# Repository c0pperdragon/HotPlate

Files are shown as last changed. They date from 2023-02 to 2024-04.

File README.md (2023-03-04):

# HotPlate

Cheap DIY solution to make a heater for hot-plate soldering.

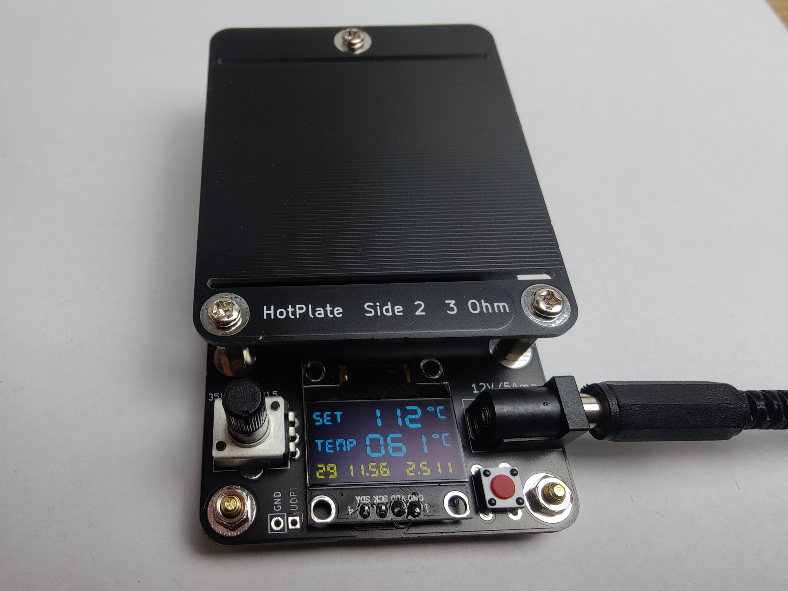
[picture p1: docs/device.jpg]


## Operating instructions

1. Plug the device to a common 12V DC power source that is able to provide 5 ampere.
2. Place the object to be soldered on the heater plate.
3. Switch on the heater with the red power button.
4. Select a target temperature (the "Set" value on the display) with the potentiometer.
5. When the solder is molten enough, turn off the heater with the red button. Note that
there is no support to automatically follow a temperature profile.

To switch the device between centigrade and fahrenheit, press the power button more than 
3 seconds when turning it on.

## Data shown on the display

* Set: Selected target temperature
* Temp: Temperature as measured

The numbers in the bottom area are used to understand the internal working and show the 
following things: 
* Duty cycle of the heater
* Supply voltage 
* Current through the top heater trace

## Theory of operation

The heater plate contains two copper traces (one at the top and one at the bottom) that can individually
be connected to the supply voltage. These traces have a resistance of about 3.5 ohm each (within
manufacturing tolerances) and will produce the heat for the process. For fine control of the output power,
the controller circuit will quickly turn each heater trace on and off.

To receive feeedback about the current temperature, the controller circuit contains a Hall-effect sensor
to monitor the electric current running through the top heater trace. Combined with the 
voltage that is also monitored, the resistance of this trace can be computed. As the specific resistance of
copper changes with temperature, the current temperature can be computed. 

Note that due to tolerances in PCB manufacturing and in the electronic parts, the temperature measurement
may be not very precise. You will need to experimentally find the best temperature setting for your specific application.

## Replacement heater plate

The repeated thermal stress on the heater will probably cause it to get damaged eventually. In this case
it is quite easy to have a replacement PCB made using the [Gerber files](heater/gerber).
As you will probably get multiple parts from your manufacturer, this should then last for a considerable 
time. 
You can also just turn over the heater plate if the top surface gets scratched or is otherwise worn out,
so you can continue to use it.

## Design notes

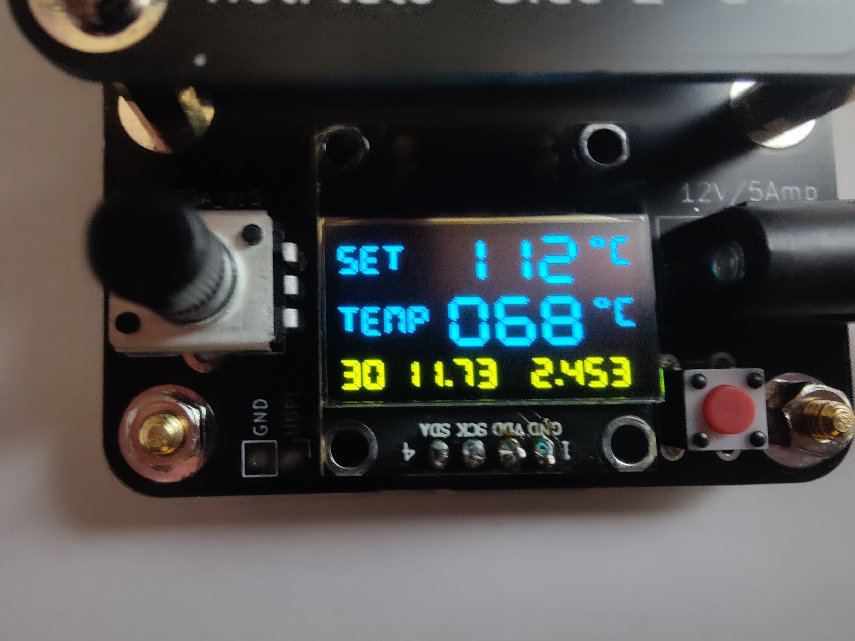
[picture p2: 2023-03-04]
docs/display.jpg

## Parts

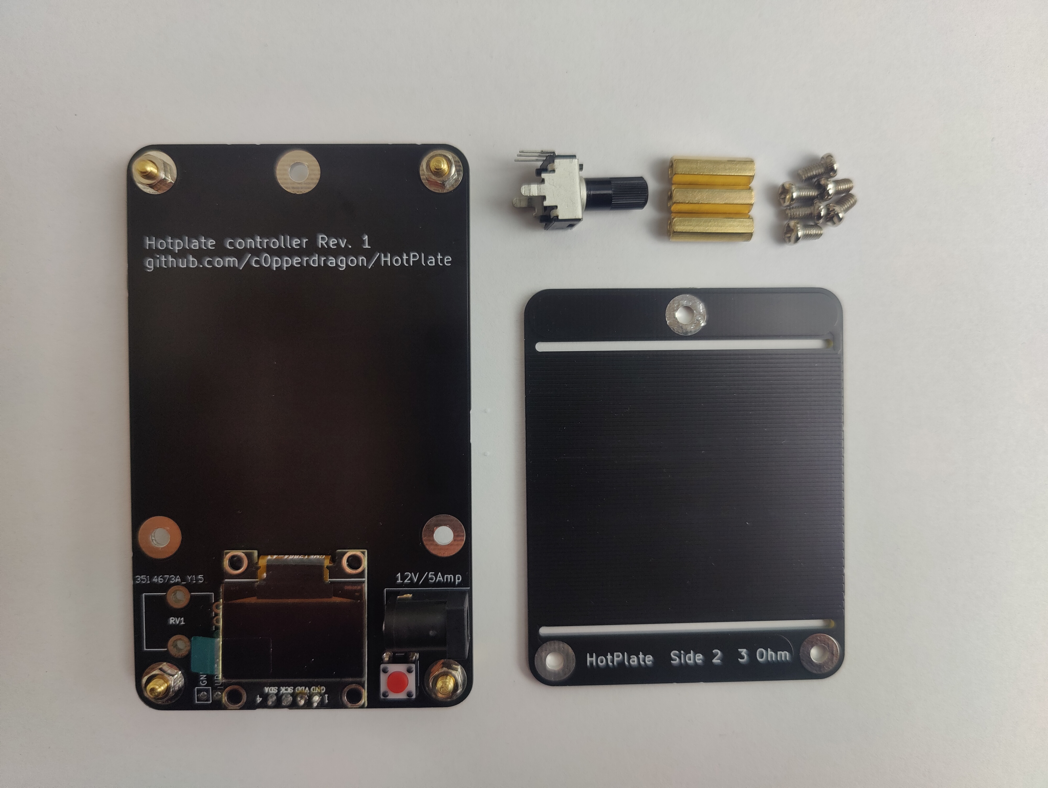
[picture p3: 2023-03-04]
docs/parts.jpg

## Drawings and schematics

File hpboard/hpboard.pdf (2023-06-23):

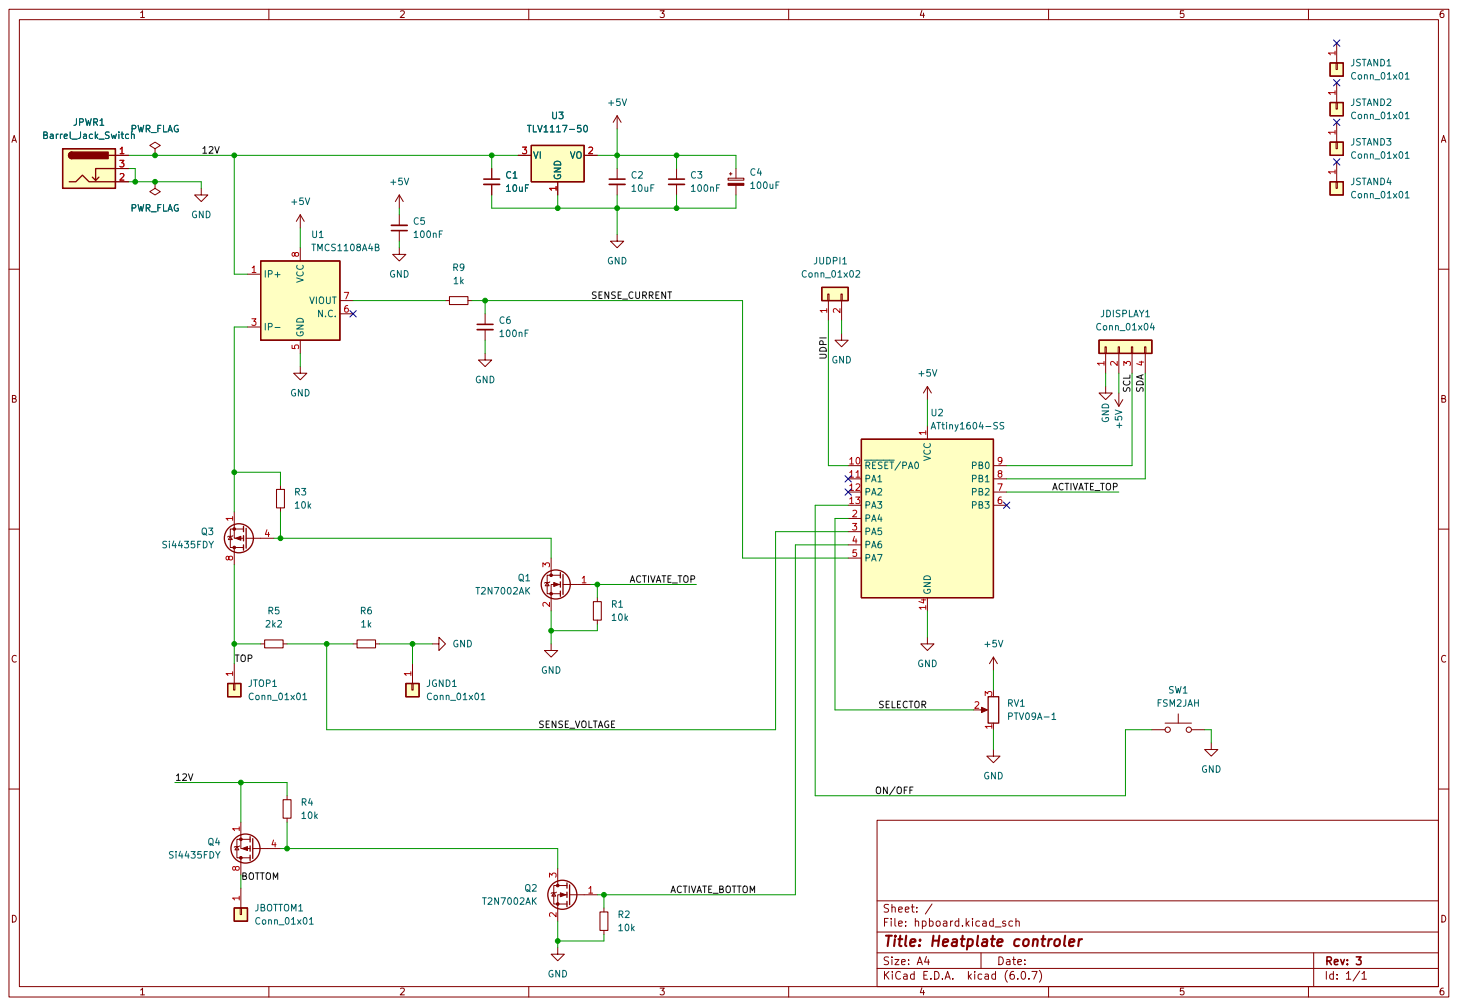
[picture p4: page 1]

File: hpboard.kicad_sch Sheet: / GND

Id: 1/1 Title: Heatplate controler

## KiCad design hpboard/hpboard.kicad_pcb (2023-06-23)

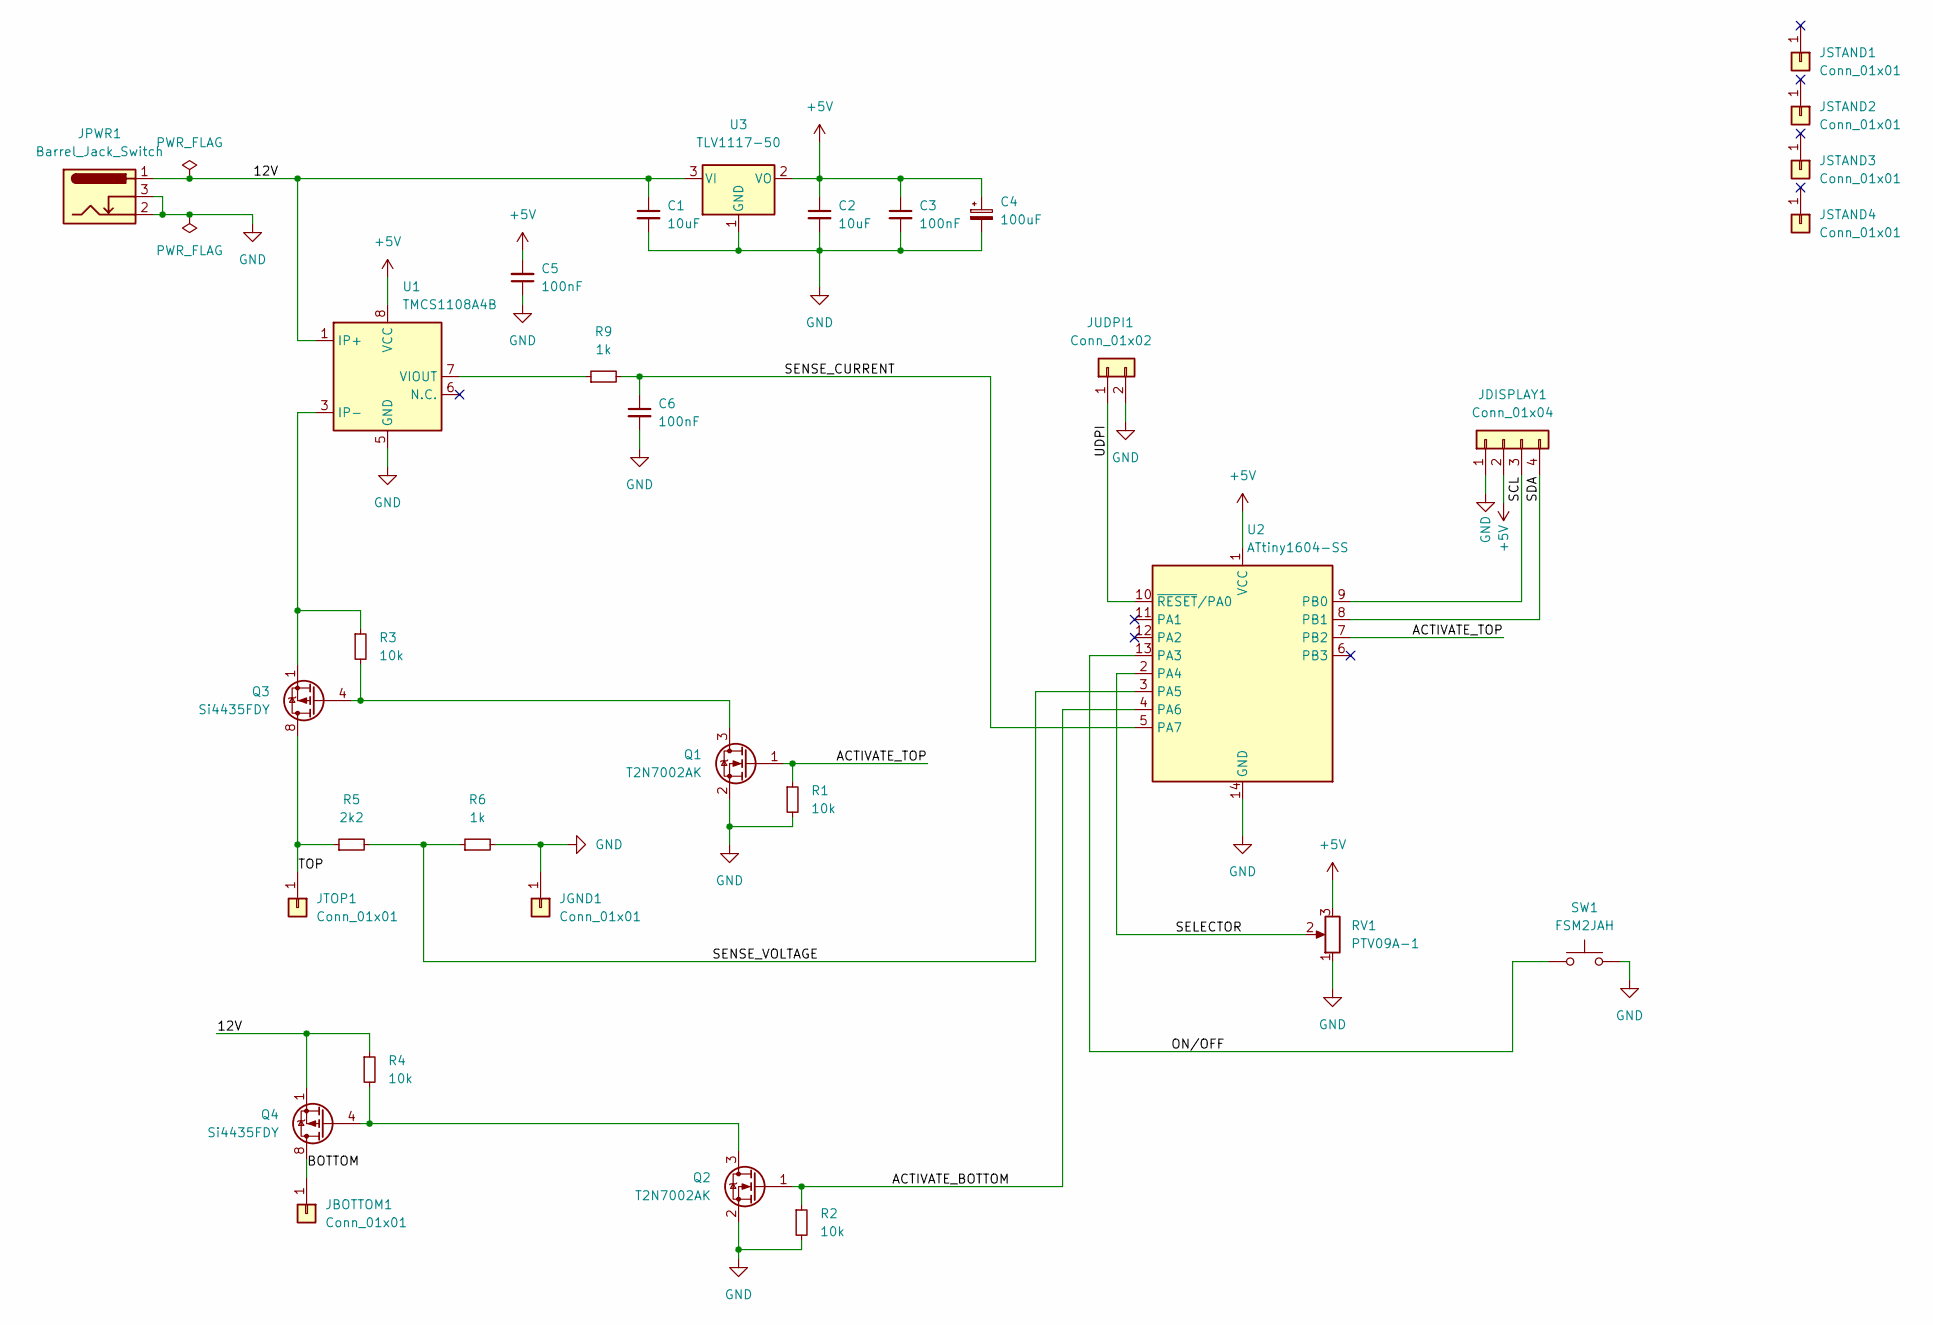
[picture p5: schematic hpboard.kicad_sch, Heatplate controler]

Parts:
C1, C2: 10uF; C_0805_2012Metric_Pad1.18x1.45mm_HandSolder
C3, C5, C6: 100nF; C_0603_1608Metric_Pad1.08x0.95mm_HandSolder
C4: 100uF; CP_EIA-3528-21_Kemet-B_Pad1.50x2.35mm_HandSolder
JBOTTOM1: Conn_01x01; MountingHole_3.2mm_Large
JDISPLAY1: Conn_01x04; PinHeader_1x04_P2.54mm_Vertical
JGND1: Conn_01x01; MountingHole_3.2mm_Large
JPWR1: Barrel_Jack_Switch; BarrelJack_Horizontal
JSTAND1, JSTAND2, JSTAND3, JSTAND4: Conn_01x01; MountingHole_3.2mm_Large
JTOP1: Conn_01x01; MountingHole_3.2mm_Large
JUDPI1: Conn_01x02; PinHeader_1x02_P2.54mm_Vertical
Q1, Q2: T2N7002AK; SOT-23
Q3, Q4: Si4435FDY; SOIC-8_3.9x4.9mm_P1.27mm
R1, R2, R3, R4: 10k; R_0805_2012Metric_Pad1.20x1.40mm_HandSolder
R5: 2k2; R_0805_2012Metric_Pad1.20x1.40mm_HandSolder
R6, R9: 1k; R_0805_2012Metric_Pad1.20x1.40mm_HandSolder
RV1: PTV09A-1; Potentiometer_Bourns_PTV09A-1_Single_Vertical
SW1: FSM2JAH; SW_PUSH_6mm
U1: TMCS1108A4B; SOIC-8_3.9x4.9mm_P1.27mm
U2: ATtiny1604-SS; SOIC-14_3.9x8.7mm_P1.27mm
U3: TLV1117-50; SOT-223-3_TabPin2

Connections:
+5V: C2.1, C3.1, C4.1, C5.2, JDISPLAY1.2, RV1.3, U1.8 (VCC), U2.1 (VCC), U3.2 (VO)
/12V: C1.1, JPWR1.1, Q4.1 (S), Q4.2 (S), Q4.3 (S), R4.1, U1.1 (IP+), U1.2 (IP+), U3.3 (VI)
/ACTIVATE_BOTTOM: Q2.1 (G), R2.1, U2.4 (PA6)
/ACTIVATE_TOP: Q1.1 (G), R1.1, U2.7 (PB2)
/BOTTOM: JBOTTOM1.1, Q4.5 (D), Q4.6 (D), Q4.7 (D), Q4.8 (D)
/ON/OFF: SW1.1, U2.13 (PA3)
/SCL: JDISPLAY1.3, U2.9 (PB0)
/SDA: JDISPLAY1.4, U2.8 (PB1)
/SELECTOR: RV1.2, U2.2 (PA4)
/SENSE_CURRENT: C6.1, R9.2, U2.5 (PA7)
/SENSE_VOLTAGE: R5.2, R6.1, U2.3 (PA5)
/TOP: JTOP1.1, Q3.5 (D), Q3.6 (D), Q3.7 (D), Q3.8 (D), R5.1
/UDPI: JUDPI1.1, U2.10 (~RESET/PA0)
GND: C1.2, C2.2, C3.2, C4.2, C5.1, C6.2, JDISPLAY1.1, JGND1.1, JPWR1.2, JPWR1.3, JUDPI1.2, Q1.2 (S), Q2.2 (S), R1.2, R2.2, R6.2, RV1.1, SW1.2, U1.5 (GND), U2.14 (GND), U3.1 (GND)
unnamed: Q1.3 (D), Q3.4 (G), R3.2
unnamed: Q2.3 (D), Q4.4 (G), R4.2
unnamed: Q3.1 (S), Q3.2 (S), Q3.3 (S), R3.1, U1.3 (IP-), U1.4 (IP-)
unnamed: R9.1, U1.7 (VIOUT)

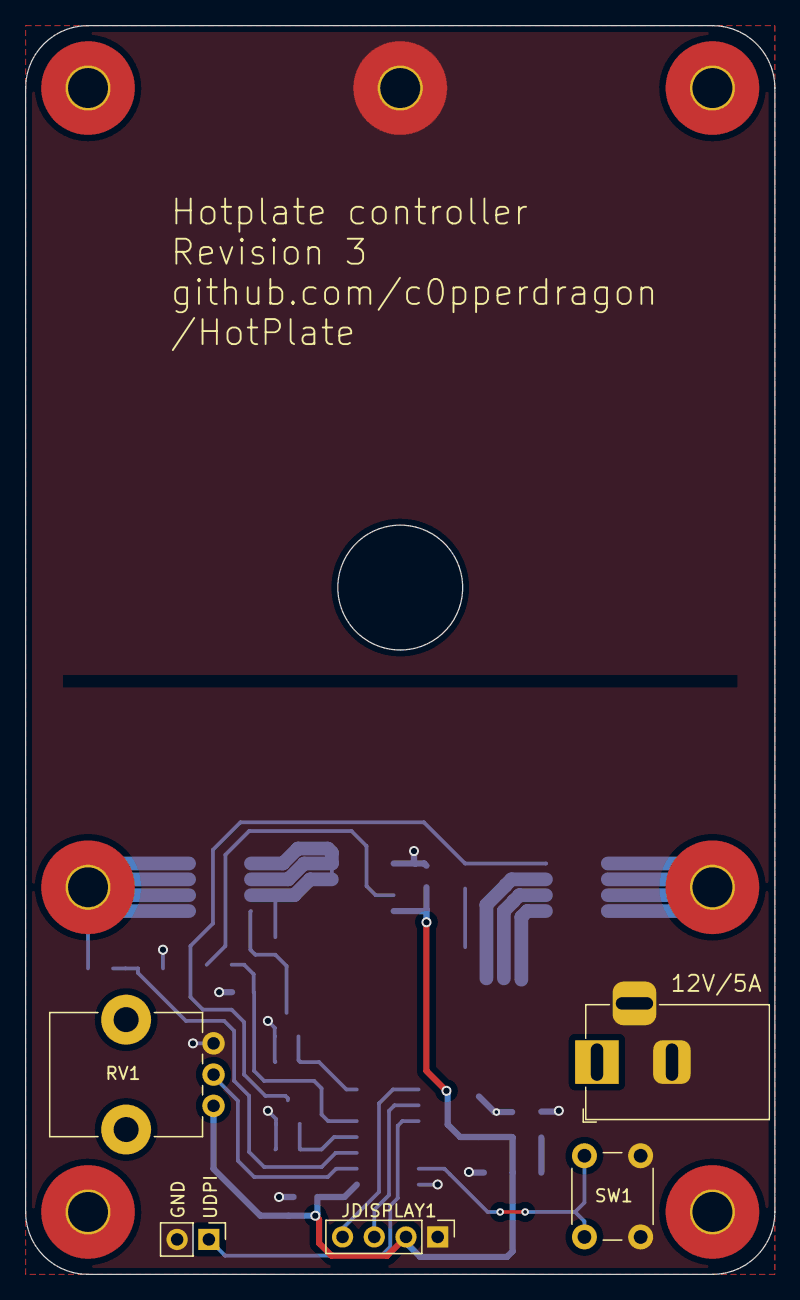
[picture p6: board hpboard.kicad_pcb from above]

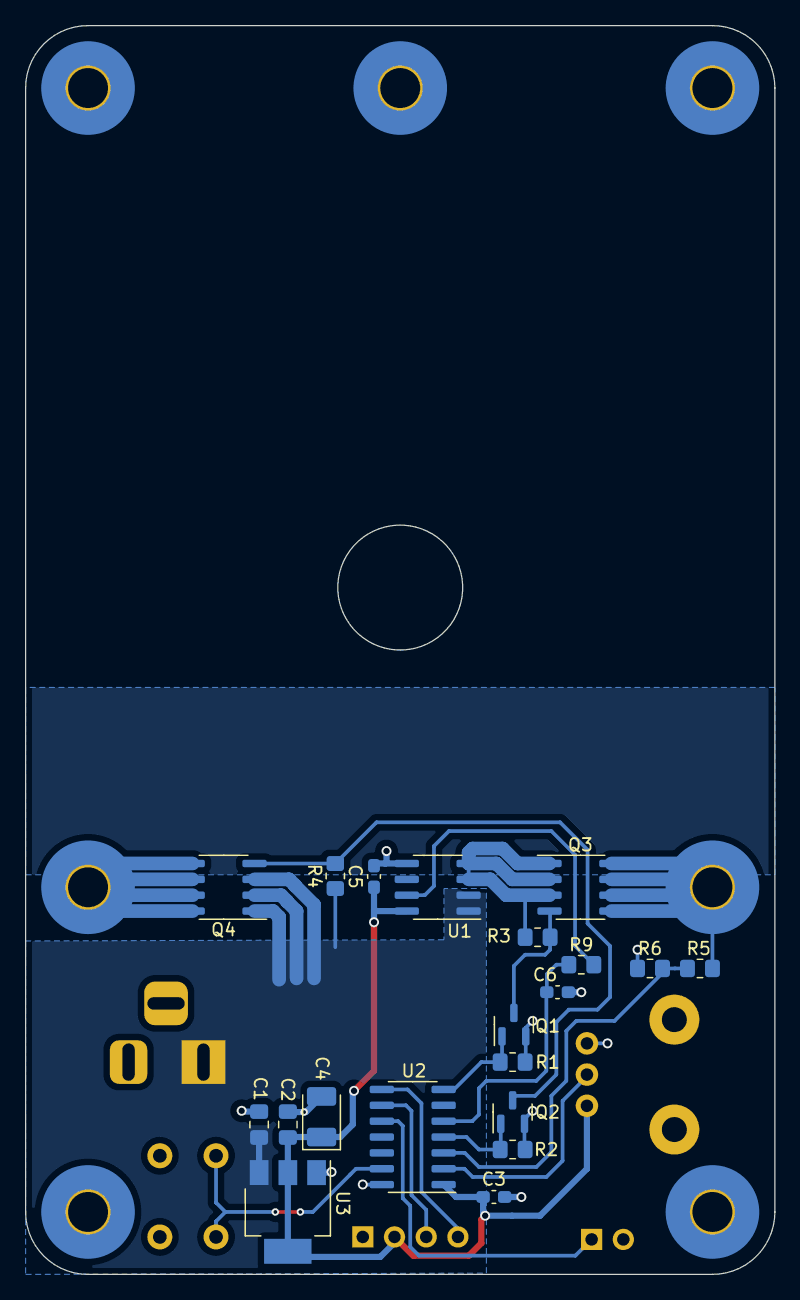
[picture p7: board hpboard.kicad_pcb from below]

Board: 2 copper layers, 60.0 x 100.0 mm, 32 parts (20 on the bottom side), 18 nets.

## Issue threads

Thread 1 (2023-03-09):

Parts List / BOM

jappyjan, 2023-03-09:
Hello,

Where can i find a BOM of Parts that i need to buy to build this project?

PS: awesome project! sad that it is already sold out on tindie, otherwise i would have bought a kit over there <3

c0pperdragon, 2023-03-09:
I have deliberately not provided a BOM to make it not _all_ too easy to copy my design. Also I can not really specify the parts, as the availability (especially for cheap OLEDs) is a bit tricky. You basically have to use what you can get from AliExpres this week.

When demand stays high, I will make more devices. But I need to raise the price a bit to not only cover my expenses but to get a little money for my time.

Anyway, I have improved the PCB design a bit and also updated the schematics. Using the schematics you should be able to order the necessary parts if you do a bit of work to figure out the IC packages sizes.

Closed 2024-03-23.

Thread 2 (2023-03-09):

Maximum temperature details

corndog2000, 2023-03-09:
Hello, this is an awesome project. I was looking on your Tindie listing, but I don't see the maximum temperature the plate can reach listed on the product page.

c0pperdragon, 2023-03-10:
Hi! I added the information to the page: 227 degrees celsius maximum.

Am Do., 9. März 2023 um 23:06 Uhr schrieb Joe Schroedl <
***@***.***>:

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

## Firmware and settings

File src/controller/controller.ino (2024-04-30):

// Program running on an ATTiny1604, 16MHz, disable millis/micros timer

#include <Wire.h>
#include <EEPROM.h>
#include "oled.h"

// -- defining pins
#define ACTIVATE_TOP     PIN_PB2
#define ACTIVATE_BOTTOM  PIN_PA6   
#define SELECTOR         PIN_PA4
#define ONOFF            PIN_PA3
#define SENSE_VOLTAGE    PIN_PA5
#define SENSE_CURRENT    PIN_PA7

// -- state of the hardware
volatile bool standby = true;
volatile int tempset = 0;  // in celsius
volatile int tempcur = 0;  // in celsius
volatile int voltage = 0;  // in mV
volatile int current = 0;  // in mA
volatile int duty = 0;     // in percent
volatile byte fahrenheit = false;

int phase = 0;    // runs from 0 to 99
bool activate_top = false;
bool activate_bottom = false;
unsigned long sum_current = 0;
unsigned long sum_voltage = 0;
unsigned long samples_taken = 0;
int onoff_presstime = 0;
int runningtime = 0;
boolean autofinish = false;
int hightemperaturetime = 0;
 
// -- configure pins and set up interrupt
void setup() 
{
  pinMode(ACTIVATE_TOP, OUTPUT);
  digitalWrite(ACTIVATE_TOP, LOW);
  pinMode(ACTIVATE_BOTTOM, OUTPUT);
  digitalWrite(ACTIVATE_BOTTOM, LOW);
  pinMode(SELECTOR, INPUT);
  pinMode(ONOFF, INPUT_PULLUP);
  pinMode(SENSE_VOLTAGE, INPUT);
  pinMode(SENSE_CURRENT, INPUT);

  Wire.begin(); 
  Wire.setClock(50000);

  TCA0.SINGLE.INTCTRL = 0x00;  // disable TCA0 interrupts
  TCA0.SINGLE.CTRLA = 0x01;          // enable timer at full speed
  TCA0.SINGLE.CTRLB = 0x00;          // normal counting mode
  TCA0.SINGLE.CTRLC = 0x00;          // no timer output on pins
  TCA0.SINGLE.CTRLD = 0x00;          // disable split mode (use single mode)
  TCA0.SINGLE.CTRLECLR = 0x03;       // normal register update, counting up
  TCA0.SINGLE.EVCTRL = 0x00;         // no event couting                
  TCA0.SINGLE.CNT = 0;
  TCA0.SINGLE.PER = 16000;
  TCA0.SINGLE.INTCTRL = 0x01;        // enable timer overflow interrupt 

  fahrenheit = EEPROM.read(0) != 255;
}

// -------------- interrupt running with 1 ms interval to control everything -------------
ISR (TCA0_OVF_vect) {
  TCA0.SINGLE.INTFLAGS = 0x01;        // clear interrupt flag
  phase = phase<99 ? phase+1 : 0;     // cycle phase

  // handle the on-off button
  byte onoff = digitalRead(ONOFF);
  if (onoff==HIGH)
  {
    onoff_presstime = 0;
  }
  else if (onoff_presstime < 32000)
  {
    onoff_presstime++;
  }
  if (onoff_presstime == 20)  // toggle standby after 20 ms button press
  {
    // doing a second press after start turns on auto-finish
    if ((!standby) && runningtime<1000) 
    {
        autofinish=true;
    }
    else
    {
      standby = !standby; 
      autofinish = false;
      hightemperaturetime = 0;
      if (standby)
      { 
        activate_top = false;
        activate_bottom = false;
        digitalWrite(ACTIVATE_TOP, LOW);
        digitalWrite(ACTIVATE_BOTTOM, LOW);
      }
      else
      {
        duty = 1;
      }
    }
  }
  if (onoff_presstime == 3000)   // toggle fahrenheit/celsius after 3 seconds
  {
    fahrenheit = ! fahrenheit;
    EEPROM.write(0, fahrenheit ? 0 : 255); 
  }
  if (onoff_presstime == 0 && autofinish && hightemperaturetime>10)
  {
      standby = true; 
      activate_top = false;
      activate_bottom = false;
      digitalWrite(ACTIVATE_TOP, LOW);
      digitalWrite(ACTIVATE_BOTTOM, LOW);
  }
    
  // do nothing else in standby
  if (standby) 
  { 
     runningtime=0; 
     return; 
  }
  // measure time since start of machine
  else if (runningtime<32000) {
    runningtime = runningtime+1;
  }
  
  tempset = 227 - (analogRead(SELECTOR) >> 3);

  if (activate_top)
  {
    int c = analogRead(SENSE_CURRENT);
    int v = analogRead(SENSE_VOLTAGE);
    sum_current += (c>=512) ? c-512 : 0;
    sum_voltage += v;
    samples_taken++;    
  }
  if (phase==0) 
  {
    voltage = (int) ( (sum_voltage * 12000) / (samples_taken * 767) );      // in millivolt
    current = (int) ( (sum_current * 1000) / (samples_taken * 81) );        // in milliampere
    int resistance = (int) ( (((long)voltage) * 1000) / current );          // in milliohm
    tempcur = 20 + (resistance-3000) / 16;                                  // in centigrade
    if (tempcur<0) { tempcur=0; }
    sum_current = 0;
    sum_voltage = 0;
    samples_taken=0;

    int power = 1300 + (tempset-155) * 10;    // in 100th watt  - estimated by experiment   
    duty = ((1000000L / current) * power) / voltage;
    if (tempcur>=tempset) 
    { 
        duty=0; 
        if (hightemperaturetime<32000) { hightemperaturetime++; }
    }       
    if (duty<5) duty=5;
    if (duty>99) duty=99;
    if (duty>50 && current>2200) { duty=50; }
  }

  int phase2 = phase<50 ? phase+50 : phase-50;
  activate_top = (phase >= 100-duty);
  activate_bottom = (phase2 >= 100-duty);
  if (!activate_top) digitalWrite(ACTIVATE_TOP, LOW);
  if (!activate_bottom) digitalWrite(ACTIVATE_BOTTOM, LOW);
  if (activate_top) digitalWrite(ACTIVATE_TOP, HIGH);
  if (activate_bottom) digitalWrite(ACTIVATE_BOTTOM, HIGH);
}

// -------------------------- handling the display ----------------------------------------

OLED display(Wire, 0x3C, NO_RESET_PIN, 1, 64, true);

bool vis_standby = false;
int vis_tempset = -1;
int vis_tempcur = -1;
int vis_voltage = -1;
int vis_current = -1;
int vis_duty = -1;
bool vis_fahrenheit = false;
bool vis_autofinish = false;

const byte background[(128/8) * 64] = {
  B00000000,B00000000,B00000000,B00000000,B00000000,B00000000,B00000000,B00000000,B00000000,B00000000,B00000000,B00000000,B00000000,B00000000,B00000000,B00000000,
  B00000000,B00000000,B00000000,B00000000,B00000000,B00000000,B00000000,B00000000,B00000000,B00000000,B00000000,B00000000,B00000000,B00000000,B11110000,B00000000,
  B00000000,B00000000,B00000000,B00000000,B00000000,B00000000,B00000000,B00000000,B00000000,B00000000,B00000000,B00000000,B00000000,B00000001,B10011000,B00000000,
  B00000000,B00000000,B00000000,B00000000,B00000000,B00000000,B00000000,B00000000,B00000000,B00000000,B00000000,B00000000,B00000000,B00000001,B10011000,B00000000,
  B01111110,B00011111,B10001111,B11110000,B00000000,B00000000,B00000000,B00000000,B00000000,B00000000,B00000000,B00000000,B00000000,B00000000,B11110000,B00000000,
  B10111100,B00101111,B00000111,B11100000,B00000000,B00000000,B00000000,B00000000,B00000000,B00000000,B00000000,B00000000,B00000000,B00000000,B00000000,B00000000,
  B11000000,B00110000,B00000001,B10000000,B00000000,B00000000,B00000000,B00000000,B00000000,B00000000,B00000000,B00000000,B00000000,B00000000,B00000000,B00000000,
  B11000000,B00110000,B00000001,B10000000,B00000000,B00000000,B00000000,B00000000,B00000000,B00000000,B00000000,B00000000,B00000000,B00000000,B00000000,B00000000,
  B11000000,B00110000,B00000001,B10000000,B00000000,B00000000,B00000000,B00000000,B00000000,B00000000,B00000000,B00000000,B00000000,B00000000,B00000000,B00000000,
  B10111100,B00101111,B00000001,B10000000,B00000000,B00000000,B00000000,B00000000,B00000000,B00000000,B00000000,B00000000,B00000000,B00000000,B00000000,B00000000,
  B00111101,B00101111,B00000001,B10000000,B00000000,B00000000,B00000000,B00000000,B00000000,B00000000,B00000000,B00000000,B00000000,B00000000,B00000000,B00000000,
  B00000011,B00110000,B00000001,B10000000,B00000000,B00000000,B00000000,B00000000,B00000000,B00000000,B00000000,B00000000,B00000000,B00000000,B00000000,B00000000,
  B00000011,B00110000,B00000001,B10000000,B00000000,B00000000,B00000000,B00000000,B00000000,B00000000,B00000000,B00000000,B00000000,B00000000,B00000000,B00000000,
  B00000011,B00110000,B00000001,B10000000,B00000000,B00000000,B00000000,B00000000,B00000000,B00000000,B00000000,B00000000,B00000000,B00000000,B00000000,B00000000,
  B00111101,B00101111,B00000000,B00000000,B00000000,B00000000,B00000000,B00000000,B00000000,B00000000,B00000000,B00000000,B00000000,B00000000,B00000000,B00000000,
  B01111110,B00011111,B10000000,B00000000,B00000000,B00000000,B00000000,B00000000,B00000000,B00000000,B00000000,B00000000,B00000000,B00000000,B00000000,B00000000,
  B00000000,B00000000,B00000000,B00000000,B00000000,B00000000,B00000000,B00000000,B00000000,B00000000,B00000000,B00000000,B00000000,B00000000,B00000000,B00000000,
  B00000000,B00000000,B00000000,B00000000,B00000000,B00000000,B00000000,B00000000,B00000000,B00000000,B00000000,B00000000,B00000000,B00000000,B00000000,B00000000,
  B00000000,B00000000,B00000000,B00000000,B00000000,B00000000,B00000000,B00000000,B00000000,B00000000,B00000000,B00000000,B00000000,B00000000,B00000000,B00000000,
  B00000000,B00000000,B00000000,B00000000,B00000000,B00000000,B00000000,B00000000,B00000000,B00000000,B00000000,B00000000,B00000000,B00000000,B00000000,B00000000,
  B00000000,B00000000,B00000000,B00000000,B00000000,B00000000,B00000000,B00000000,B00000000,B00000000,B00000000,B00000000,B00000000,B00000000,B00000000,B00000000,
  
  B00000000,B00000000,B00000000,B00000000,B00000000,B00000000,B00000000,B00000000,B00000000,B00000000,B00000000,B00000000,B00000000,B00000000,B00000000,B00000000,
  B00000000,B00000000,B00000000,B00000000,B00000000,B00000000,B00000000,B00000000,B00000000,B00000000,B00000000,B00000000,B00000000,B00000000,B00000000,B00000000,
  B00000000,B00000000,B00000000,B00000000,B00000000,B00000000,B00000000,B00000000,B00000000,B00000000,B00000000,B00000000,B00000000,B00000000,B00000000,B00000000,  
  B00000000,B00000000,B00000000,B00000000,B00000000,B00000000,B00000000,B00000000,B00000000,B00000000,B00000000,B00000000,B00000000,B00000000,B00000000,B00000000,
  B00000000,B00000000,B00000000,B00000000,B00000000,B00000000,B00000000,B00000000,B00000000,B00000000,B00000000,B00000000,B00000000,B00000000,B00000000,B00000000,
  B00000000,B00000000,B00000000,B00000000,B00000000,B00000000,B00000000,B00000000,B00000000,B00000000,B00000000,B00000000,B00000000,B00000000,B00000000,B00000000,
  
  B00000000,B00000000,B00000000,B00000000,B00000000,B00000000,B00000000,B00000000,B00000000,B00000000,B00000000,B00000000,B00000000,B00000000,B00000000,B00000000,
  B00000000,B00000000,B00000000,B00000000,B00000000,B00000000,B00000000,B00000000,B00000000,B00000000,B00000000,B00000000,B00000000,B00000000,B11110000,B00000000,
  B00000000,B00000000,B00000000,B00000000,B00000000,B00000000,B00000000,B00000000,B00000000,B00000000,B00000000,B00000000,B00000000,B00000001,B10011000,B00000000,
  B00000000,B00000000,B00000000,B00000000,B00000000,B00000000,B00000000,B00000000,B00000000,B00000000,B00000000,B00000000,B00000000,B00000001,B10011000,B00000000,
  B11111111,B00011111,B10000111,B11100001,B11111000,B00000000,B00000000,B00000000,B00000000,B00000000,B00000000,B00000000,B00000000,B00000000,B11110000,B00000000,
  B01111110,B00101111,B00001011,B11010010,B11110100,B00000000,B00000000,B00000000,B00000000,B00000000,B00000000,B00000000,B00000000,B00000000,B00000000,B00000000,
  B00011000,B00110000,B00001101,B10110011,B00001100,B00000000,B00000000,B00000000,B00000000,B00000000,B00000000,B00000000,B00000000,B00000000,B00000000,B00000000,
  B00011000,B00110000,B00001100,B00110011,B00001100,B00000000,B00000000,B00000000,B00000000,B00000000,B00000000,B00000000,B00000000,B00000000,B00000000,B00000000,
  B00011000,B00110000,B00001100,B00110011,B00001100,B00000000,B00000000,B00000000,B00000000,B00000000,B00000000,B00000000,B00000000,B00000000,B00000000,B00000000,
  B00011000,B00101111,B00001000,B00010010,B11110100,B00000000,B00000000,B00000000,B00000000,B00000000,B00000000,B00000000,B00000000,B00000000,B00000000,B00000000,
  B00011000,B00101111,B00001000,B00010010,B11110000,B00000000,B00000000,B00000000,B00000000,B00000000,B00000000,B00000000,B00000000,B00000000,B00000000,B00000000,
  B00011000,B00110000,B00001100,B00110011,B00000000,B00000000,B00000000,B00000000,B00000000,B00000000,B00000000,B00000000,B00000000,B00000000,B00000000,B00000000,
  B00011000,B00110000,B00001100,B00110011,B00000000,B00000000,B00000000,B00000000,B00000000,B00000000,B00000000,B00000000,B00000000,B00000000,B00000000,B00000000,  
  B00011000,B00110000,B00001100,B00110011,B00000000,B00000000,B00000000,B00000000,B00000000,B00000000,B00000000,B00000000,B00000000,B00000000,B00000000,B00000000,
  B00000000,B00101111,B00001000,B00010010,B00000000,B00000000,B00000000,B00000000,B00000000,B00000000,B00000000,B00000000,B00000000,B00000000,B00000000,B00000000,
  B00000000,B00011111,B10000000,B00000000,B00000000,B00000000,B00000000,B00000000,B00000000,B00000000,B00000000,B00000000,B00000000,B00000000,B00000000,B00000000,
  B00000000,B00000000,B00000000,B00000000,B00000000,B00000000,B00000000,B00000000,B00000000,B00000000,B00000000,B00000000,B00000000,B00000000,B00000000,B00000000,
  B00000000,B00000000,B00000000,B00000000,B00000000,B00000000,B00000000,B00000000,B00000000,B00000000,B00000000,B00000000,B00000000,B00000000,B00000000,B00000000,
  B00000000,B00000000,B00000000,B00000000,B00000000,B00000000,B00000000,B00000000,B00000000,B00000000,B00000000,B00000000,B00000000,B00000000,B00000000,B00000000,
  B00000000,B00000000,B00000000,B00000000,B00000000,B00000000,B00000000,B00000000,B00000000,B00000000,B00000000,B00000000,B00000000,B00000000,B00000000,B00000000,
  B00000000,B00000000,B00000000,B00000000,B00000000,B00000000,B00000000,B00000000,B00000000,B00000000,B00000000,B00000000,B00000000,B00000000,B00000000,B00000000,
  
  B00000000,B00000000,B00000000,B00000000,B00000000,B00000000,B00000000,B00000000,B00000000,B00000000,B00000000,B00000000,B00000000,B00000000,B00000000,B00000000,
  B00000000,B00000000,B00000000,B00000000,B00000000,B00000000,B00000000,B00000000,B00000000,B00000000,B00000000,B00000000,B00000000,B00000000,B00000000,B00000000,
  B00000000,B00000000,B00000000,B00000000,B00000000,B00000000,B00000000,B00000000,B00000000,B00000000,B00000000,B00000000,B00000000,B00000000,B00000000,B00000000,
  B00000000,B00000000,B00000000,B00000000,B00000000,B00000000,B00000000,B00000000,B00000000,B00000000,B00000000,B00000000,B00000000,B00000000,B00000000,B00000000,
  B00000000,B00000000,B00000000,B00000000,B00000000,B00000000,B00000000,B00000000,B00000000,B00000000,B00000000,B00000000,B00000000,B00000000,B00000000,B00000000,
  B00000000,B00000000,B00000000,B00000000,B00000000,B00000000,B00000000,B00000000,B00000000,B00000000,B00000000,B00000000,B00000000,B00000000,B00000000,B00000000,
  B00000000,B00000000,B00000000,B00000000,B00000000,B00000000,B00000000,B00000000,B00000000,B00000000,B00000000,B00000000,B00000000,B00000000,B00000000,B00000000,
  B00000000,B00000000,B00000000,B00000000,B00000000,B00000000,B00000000,B00000000,B00000000,B00000000,B00000000,B00000000,B00000000,B00000000,B00000000,B00000000,
  B00000000,B00000000,B00000000,B00000000,B00000000,B00000000,B00000000,B00000000,B00000000,B00000000,B00000000,B00000000,B00000000,B00000000,B00000000,B00000000,
  B00000000,B00000000,B00000000,B00000000,B00000000,B00000000,B00000000,B00000000,B00000000,B00000000,B00000000,B00000000,B00000000,B00000000,B00000000,B00000000,
  B00000000,B00000000,B00000000,B00000000,B00000000,B00000000,B00000000,B00000000,B00000000,B00000000,B00000000,B00000000,B00000000,B00000000,B00000000,B00000000,
  B00000000,B00000000,B00000000,B00000000,B00000000,B00000000,B00000000,B00000000,B00000000,B00000000,B00000000,B00000000,B00000000,B00000000,B00000000,B00000000,
  B00000000,B00000000,B00000000,B00000000,B00000000,B00000000,B00000000,B00000000,B00000000,B00000000,B00000000,B00000000,B00000000,B00000000,B00000000,B00000000,
  B00000000,B00000000,B00000000,B00000000,B00000000,B00000110,B00000000,B00000000,B00000000,B00000000,B00000000,B00001100,B00000000,B00000000,B00000000,B00000000,
  B00000000,B00000000,B00000000,B00000000,B00000000,B00000110,B00000000,B00000000,B00000000,B00000000,B00000000,B00001100,B00000000,B00000000,B00000000,B00000000,
  B00000000,B00000000,B00000000,B00000000,B00000000,B00000000,B00000000,B00000000,B00000000,B00000000,B00000000,B00000000,B00000000,B00000000,B00000000,B00000000,
};
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
void loop() 
{
  bool b;
  int v;
  
  noInterrupts(); b = standby; interrupts();
  if (b!=vis_standby) 
  {
    vis_standby = b;
    if (vis_standby) 
    {
      display.set_power(false);
    }
    else 
    {
      display.init();
      display.rotate_180(true);
      display.direct(0,0,128,8,background,16);
      vis_tempset = -1;
      vis_tempcur = -1;
      vis_voltage = -1;
      vis_current = -1;
      vis_duty = -1;
      vis_fahrenheit = ! fahrenheit;
    }
  }
  
  noInterrupts(); b = fahrenheit; interrupts();
  if (b!=vis_fahrenheit) 
  {
    vis_fahrenheit = b;
    vis_tempset = -1;
    vis_tempcur = -1;
    int d =  b ? 11 : 10;
    display.direct(120, 0, 8, 2, smalldigits+d + 3*12, 12);
    display.direct(120, 3, 8, 2, smalldigits+d, 12);
  }
  
  noInterrupts(); v = tempset; interrupts();
  if (v!=vis_tempset)  // v<vis_tempset-1 || v>vis_tempset) 
  {
    vis_tempset = v;
    big_number(48,0,3, fahrenheit ? 32 + v*9/5 :v, 3);
  }

  noInterrupts(); v = tempcur; interrupts();
  if (v<vis_tempcur-1 || v>vis_tempcur) 
  {
    vis_tempcur = v;
    big_number(48,3,0, fahrenheit ? 32 + v*9/5 :v, 3);
  }

  noInterrupts(); v = duty; interrupts();
  if (v!=vis_duty) 
  {
    vis_duty = v;
    if (v>5) {
      small_number(0,6,v,2);
    }
    else {
      display.direct(0, 6, 20, 1, background, 1);
      display.direct(0, 7, 20, 1, background, 1);
    }
  }

  noInterrupts(); v = voltage/10; interrupts();
  if (v!=vis_voltage) 
  {
    vis_voltage = v;
    small_number(25,6,v/100,2);
    small_number(48,6,v%100,2);
  }
  
  noInterrupts(); v = current; interrupts();
  if (v!=vis_current) 
  {
    vis_current = v;
    small_number(82,6,v/1000,1);
    small_number(95,6,v%1000,3);
  }
  
  noInterrupts(); b = autofinish; interrupts();
  if (b!=vis_autofinish) 
  {
    vis_autofinish = b;
    display.direct(0,  0, 8, 2, smalldigits+0  + 1*12, 12);
    display.direct(10, 0, 8, 2, smalldigits+11 + 1*12, 12);
    display.direct(20, 0, 8, 2, smalldigits+11 + 1*12, 12);
  }
}
    

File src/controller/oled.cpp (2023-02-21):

#include <Arduino.h>
#include "oled.h"

static const uint8_t oled_font6x8 [] PROGMEM = {
    0x00, 0x00, 0x00, 0x00, 0x00, 0x00, // sp
    0x00, 0x00, 0x00, 0x2f, 0x00, 0x00, // !
    0x00, 0x00, 0x07, 0x00, 0x07, 0x00, // "
    0x00, 0x14, 0x7f, 0x14, 0x7f, 0x14, // #
    0x00, 0x24, 0x2a, 0x7f, 0x2a, 0x12, // $
    0x00, 0x62, 0x64, 0x08, 0x13, 0x23, // %
    0x00, 0x36, 0x49, 0x55, 0x22, 0x50, // &
    0x00, 0x00, 0x05, 0x03, 0x00, 0x00, // '
    0x00, 0x00, 0x1c, 0x22, 0x41, 0x00, // (
    0x00, 0x00, 0x41, 0x22, 0x1c, 0x00, // )
    0x00, 0x14, 0x08, 0x3E, 0x08, 0x14, // *
    0x00, 0x08, 0x08, 0x3E, 0x08, 0x08, // +
    0x00, 0x00, 0x00, 0xA0, 0x60, 0x00, // ,
    0x00, 0x08, 0x08, 0x08, 0x08, 0x08, // -
    0x00, 0x00, 0x60, 0x60, 0x00, 0x00, // .
    0x00, 0x20, 0x10, 0x08, 0x04, 0x02, // /
    0x00, 0x3E, 0x51, 0x49, 0x45, 0x3E, // 0
    0x00, 0x00, 0x42, 0x7F, 0x40, 0x00, // 1
    0x00, 0x42, 0x61, 0x51, 0x49, 0x46, // 2
    0x00, 0x21, 0x41, 0x45, 0x4B, 0x31, // 3
    0x00, 0x18, 0x14, 0x12, 0x7F, 0x10, // 4
    0x00, 0x27, 0x45, 0x45, 0x45, 0x39, // 5
    0x00, 0x3C, 0x4A, 0x49, 0x49, 0x30, // 6
    0x00, 0x01, 0x71, 0x09, 0x05, 0x03, // 7
    0x00, 0x36, 0x49, 0x49, 0x49, 0x36, // 8
    0x00, 0x06, 0x49, 0x49, 0x29, 0x1E, // 9
    0x00, 0x00, 0x36, 0x36, 0x00, 0x00, // :
    0x00, 0x00, 0x56, 0x36, 0x00, 0x00, // ;
    0x00, 0x08, 0x14, 0x22, 0x41, 0x00, // <
    0x00, 0x14, 0x14, 0x14, 0x14, 0x14, // =
    0x00, 0x00, 0x41, 0x22, 0x14, 0x08, // >
    0x00, 0x02, 0x01, 0x51, 0x09, 0x06, // ?
    0x00, 0x32, 0x49, 0x59, 0x51, 0x3E, // @
    0x00, 0x7C, 0x12, 0x11, 0x12, 0x7C, // A
    0x00, 0x7F, 0x49, 0x49, 0x49, 0x36, // B
    0x00, 0x3E, 0x41, 0x41, 0x41, 0x22, // C
    0x00, 0x7F, 0x41, 0x41, 0x22, 0x1C, // D
    0x00, 0x7F, 0x49, 0x49, 0x49, 0x41, // E
    0x00, 0x7F, 0x09, 0x09, 0x09, 0x01, // F
    0x00, 0x3E, 0x41, 0x49, 0x49, 0x7A, // G
    0x00, 0x7F, 0x08, 0x08, 0x08, 0x7F, // H
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
    0x00, 0x55, 0x2A, 0x55, 0x2A, 0x55, // backslash
    0x00, 0x00, 0x41, 0x41, 0x7F, 0x00, // ]
    0x00, 0x04, 0x02, 0x01, 0x02, 0x04, // ^
    0x00, 0x40, 0x40, 0x40, 0x40, 0x40, // _
    0x00, 0x00, 0x01, 0x02, 0x04, 0x00, // '
    0x00, 0x20, 0x54, 0x54, 0x54, 0x78, // a
    0x00, 0x7F, 0x48, 0x44, 0x44, 0x38, // b
    0x00, 0x38, 0x44, 0x44, 0x44, 0x20, // c
    0x00, 0x38, 0x44, 0x44, 0x48, 0x7F, // d
    0x00, 0x38, 0x54, 0x54, 0x54, 0x18, // e
    0x00, 0x08, 0x7E, 0x09, 0x01, 0x02, // f
    0x00, 0x18, 0xA4, 0xA4, 0xA4, 0x7C, // g
    0x00, 0x7F, 0x08, 0x04, 0x04, 0x78, // h
    0x00, 0x00, 0x44, 0x7D, 0x40, 0x00, // i
    0x00, 0x40, 0x80, 0x84, 0x7D, 0x00, // j
    0x00, 0x7F, 0x10, 0x28, 0x44, 0x00, // k
    0x00, 0x00, 0x41, 0x7F, 0x40, 0x00, // l
    0x00, 0x7C, 0x04, 0x18, 0x04, 0x78, // m
    0x00, 0x7C, 0x08, 0x04, 0x04, 0x78, // n
    0x00, 0x38, 0x44, 0x44, 0x44, 0x38, // o
    0x00, 0xFC, 0x24, 0x24, 0x24, 0x18, // p
    0x00, 0x18, 0x24, 0x24, 0x18, 0xFC, // q
    0x00, 0x7C, 0x08, 0x04, 0x04, 0x08, // r
    0x00, 0x48, 0x54, 0x54, 0x54, 0x20, // s
    0x00, 0x04, 0x3F, 0x44, 0x40, 0x20, // t
    0x00, 0x3C, 0x40, 0x40, 0x20, 0x7C, // u
    0x00, 0x1C, 0x20, 0x40, 0x20, 0x1C, // v
    0x00, 0x3C, 0x40, 0x30, 0x40, 0x3C, // w
    0x00, 0x44, 0x28, 0x10, 0x28, 0x44, // x
    0x00, 0x1C, 0xA0, 0xA0, 0xA0, 0x7C, // y
    0x00, 0x44, 0x64, 0x54, 0x4C, 0x44, // z
    0x00, 0x00, 0x08, 0x77, 0x41, 0x00, // {
    0x00, 0x00, 0x00, 0x63, 0x00, 0x00, // ¦
    0x00, 0x00, 0x41, 0x77, 0x08, 0x00, // }
    0x00, 0x08, 0x04, 0x08, 0x08, 0x04, // ~
    0x00, 0x3D, 0x40, 0x40, 0x20, 0x7D, // ü
    0x00, 0x3D, 0x40, 0x40, 0x40, 0x3D, // Ü
    0x00, 0x21, 0x54, 0x54, 0x54, 0x79, // ä
    0x00, 0x7D, 0x12, 0x11, 0x12, 0x7D, // Ä
    0x00, 0x39, 0x44, 0x44, 0x44, 0x39, // ö
    0x00, 0x3D, 0x42, 0x42, 0x42, 0x3D, // Ö
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
};

OLED::OLED(TwoWire& i2c, uint8_t i2c_address, uint8_t reset_pin, uint_fast8_t width, uint_fast8_t height, bool isSH1106) : 
i2c(i2c),
i2c_address(i2c_address),
reset_pin(reset_pin),
width(width),
height(height),
isSH1106(isSH1106),
pages((height + 7) / 8),
bufsize(static_cast<uint_least16_t> (pages*width))
{
    this->buffer = static_cast<uint8_t*>(malloc(bufsize)); // two dimensional array of n pages each of n columns.
}

OLED::~OLED()
{
    free(buffer);
}


void OLED::init()
{    
    if (reset_pin != NO_RESET_PIN)
    {
        pinMode(reset_pin, OUTPUT);
        digitalWrite(reset_pin, LOW);
        delay(10);
        digitalWrite(reset_pin, HIGH);
    }
    delay(100);
    i2c.beginTransmission(i2c_address);
    i2c.write(0x00); // command
    i2c.write(0xAE); // display off
    i2c.write(0xD5); // clock divider
    i2c.write(0x80); 
    i2c.write(0xA8); // multiplex ratio
    i2c.write(height - 1); 
    i2c.write(0xD3); // no display offset
    i2c.write(0x00); 
    i2c.write(0x40); // start line address=0
    i2c.write(0x8D); // enable charge pump
    i2c.write(0x14); 
    i2c.write(0x20); // memory adressing mode=horizontal
    i2c.write(0x00); 
    i2c.write(0xA1); // segment remapping mode
    i2c.write(0xC8); // COM output scan direction
    if (width == 128 && height == 32)
    {
        i2c.write(0xDA); // com pins hardware configuration
        i2c.write(0x02); 
    }
    else if (width == 128 && height == 64)
    {
        i2c.write(0xDA); // com pins hardware configuration
        i2c.write(0x12); 
    }
    else if (width == 96 && height == 16)
    {
        i2c.write(0xDA); // com pins hardware configuration
        i2c.write(0x02); 
    }
    i2c.write(0x81); // contrast control
    i2c.write(0x40);
    i2c.write(0xD9); // pre-charge period
    i2c.write(0x22); // or is 0xF1 better?
    i2c.write(0xDB); // set vcomh deselect level
    i2c.write(0x20); // or is 0x40 better?
    i2c.write(0xA4); // output RAM to display
    i2c.write(0xA6); // display mode A6=normal, A7=inverse
    i2c.write(0x2E); // stop scrolling
    i2c.endTransmission();
    delay(100);

    // Clear and send buffer
    clear();
    display();

    // Switch display on
    set_power(true);
}

void OLED::set_power(bool enable)
{
    i2c.beginTransmission(i2c_address);
    i2c.write(0x00); // command
    if (enable)
    {
        i2c.write(0x8D); // enable charge pump
        i2c.write(0x14);
        i2c.write(0xAF); // display on
    }
    else
    {
        i2c.write(0xAE); // display off
        i2c.write(0x8D); // disable charge pump
        i2c.write(0x10);
    }
    i2c.endTransmission();
}

void OLED::set_invert(bool enable)
{
    i2c.beginTransmission(i2c_address);
    i2c.write(0x00); // command
    if (enable)
    {
        i2c.write(0xA7); // invert display
    }
    else
    {
        i2c.write(0xA6); // normal display
    }
    i2c.endTransmission();
}
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

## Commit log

2023-01-19 Design schematics
    [TraceCalculation.ods, heater.kicad_pcb, heater.kicad_sch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]
2023-01-20 Design heating plate
    [TraceCalculation.ods, heater.kicad_pcb, heater.kicad_sch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]
2023-01-20 Add some space between ICs
    [hpboard.kicad_pcb]
2023-02-20 Less noise in current sensing. Faster regulation.
    [hpboard.kicad_pcb, hpboard.kicad_sch]
2023-02-21 Support Fahrenheit display Fix silkscreen on heater
    [heater.kicad_pcb]
2023-02-22 Turn on simultanious surface heating earlier.
2023-02-22 Remove unnecessary pull-ups
    [hpboard.kicad_pcb, hpboard.kicad_sch]
2023-02-24 Improve temperature control
2023-03-02 Calibrate temperature sensing
2023-03-04 Fix link to gerber
2023-03-09 Change text on heater plate
    [heater.kicad_pcb]
2023-03-09 Rework PCB for better soldering
    [hpboard.kicad_pcb, hpboard.kicad_sch]
2023-03-09 Update schematic PDF
2023-06-23 Add hole to PCB to allow the hotplate to SMD-solder its own clone. Switch GND and VCC on display module to support slimmer and more common variant
    [hpboard.kicad_pcb, hpboard.kicad_sch]
2024-04-30 Fine-tune temperature sensing
